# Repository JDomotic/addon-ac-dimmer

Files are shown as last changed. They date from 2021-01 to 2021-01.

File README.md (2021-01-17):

# AC Dimmer Addon
This is a custom made 2 channel AC dimmer addon which fits on the back of the [Wireless sensor board](https://github.com/JDomotic/esp12-wireless-sensor-board) .

The board can receive commands over uart with configurable transition speed per channel. 
It also has a 230VAC button input and a 230VAC power meter

## Version 1 | 05-01-2019
**Features**:
* Onboard 1A 3.3v AC power supply
* Zero cross detection 
* Two triac for 230VAC dimming with a total power of 4 amps (or 2*2 amps)
* Input for a 230VAC button 
* 230VAC power meter  
* Small formfactor, fits in electric wall boxes 

**Schematic**

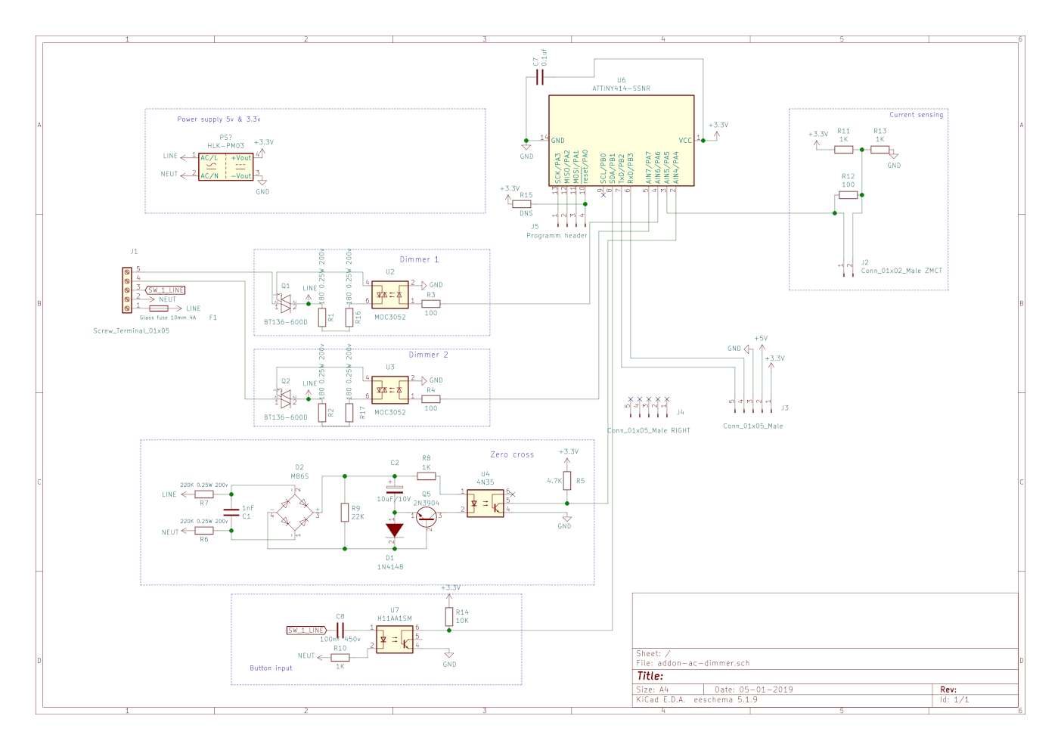
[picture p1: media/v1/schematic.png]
Schematic V1


**BOM**

**Ref**|**Qnty**|**Value**|**Footprint**|**Vendor (LCSC)**
:-----: | :-----: | :-----: | :-----: | :-----:
C1,|1|1nF|Capacitor\_SMD:C\_1206\_3216Metric\_Pad1.42x1.75mm\_HandSolder|C152975
C2,|1|10uF/10V|Capacitor\_THT:CP\_Radial\_D4.0mm\_P2.00mm|C191532
C7,|1|0.1uf|Capacitor\_SMD:C\_1206\_3216Metric\_Pad1.42x1.75mm\_HandSolder|C128353
C8,|1|100nF 450v|Capacitor\_SMD:C\_1206\_3216Metric\_Pad1.42x1.75mm\_HandSolder|C106025
D1,|1|1N4148|Diode\_SMD:D\_SOD-123|C184882
D2,|1|MB6S|Package\_TO\_SOT\_SMD:TO-269AA|C83867
F1,|1|Glass fuse 10mm 4A|Resistor\_THT:R\_Axial\_DIN0411\_L9.9mm\_D3.6mm\_P12.70mm\_Horizontal|C140492
J1,|1|Screw\_Terminal\_01x05|TerminalBlock\_RND:TerminalBlock\_RND\_205-00279\_1x05\_P5.00mm\_Vertical|C163149
J1,|1|Screw\_Terminal\_01x05|TerminalBlock\_RND:TerminalBlock\_RND\_205-00279\_1x05\_P5.00mm\_Vertical|C163148
J2,|1|Conn\_01x02\_Male ZMCT|Connector\_PinHeader\_2.54mm:PinHeader\_1x02\_P2.54mm\_Vertical|-
J3,|1|Conn\_01x05\_Male|Connector\_PinHeader\_2.54mm:PinHeader\_1x05\_P2.54mm\_Vertical|-
J4,|1|Conn\_01x05\_Male RIGHT|Connector\_PinHeader\_2.54mm:PinHeader\_1x05\_P2.54mm\_Vertical|-
J5,|1|Programm header|Connector\_PinHeader\_2.54mm:PinHeader\_1x04\_P2.54mm\_Vertical|-
Q1, Q2,|2|BT136-600D|Package\_TO\_SOT\_THT:TO-220-3\_Vertical|C130426
Q1, Q2,|2|TO-220 heatsink|TO-220 heatsink|C4650
Q5,|1|2N3904|Package\_TO\_SOT\_SMD:SOT-23|C18536
R1, R2, R16, R17,|4|180 0.25W 200v|Resistor\_SMD:R\_1210\_3225Metric\_Pad1.42x2.65mm\_HandSolder|C171148
R3, R4, R12,|3|100|Resistor\_SMD:R\_0805\_2012Metric\_Pad1.15x1.40mm\_HandSolder|-
R5,|1|4.7K|Resistor\_SMD:R\_0805\_2012Metric\_Pad1.15x1.40mm\_HandSolder|C328399
R6, R7,|2|220K 0.25W 200v|Resistor\_SMD:R\_0805\_2012Metric\_Pad1.15x1.40mm\_HandSolder|C352118
R8, R11, R13,|3|1K|Resistor\_SMD:R\_0805\_2012Metric\_Pad1.15x1.40mm\_HandSolder|C95781
R9,|1|22K|Resistor\_SMD:R\_0805\_2012Metric\_Pad1.15x1.40mm\_HandSolder|-
R10,|1|1K|Resistor\_SMD:R\_1206\_3216Metric\_Pad1.30x1.75mm\_HandSolder|C175514
R14,|1|10K|Resistor\_SMD:R\_0805\_2012Metric\_Pad1.15x1.40mm\_HandSolder|C103904
R15,|1|DNS|Resistor\_SMD:R\_0805\_2012Metric\_Pad1.15x1.40mm\_HandSolder|C103904
U1,|1|HLK-PM02|Power\_Supply:HLK-PM03| 
U2, U3,|2|MOC3052|Package\_DIP:SMDIP-6\_W7.62mm|C115471
U4,|1|4N35|Package\_DIP:SMDIP-6\_W7.62mm|C115444
U6,|1|ATTINY414-SSNR|Package\_SO:SOIC-14\_3.9x8.7mm\_P1.27mm|C189365
U7,|1|H11AA1SM|Package\_DIP:SMDIP-6\_W7.62mm|C184383

**Render**

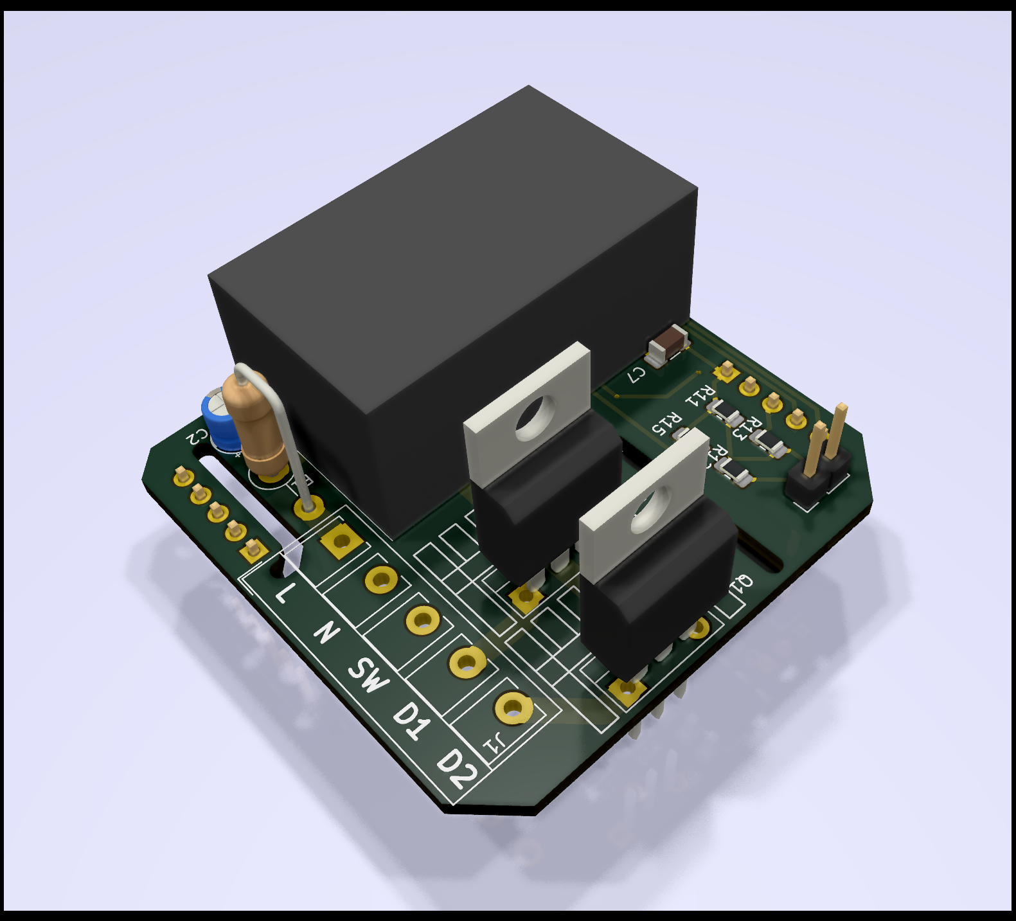
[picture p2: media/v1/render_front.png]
Render front

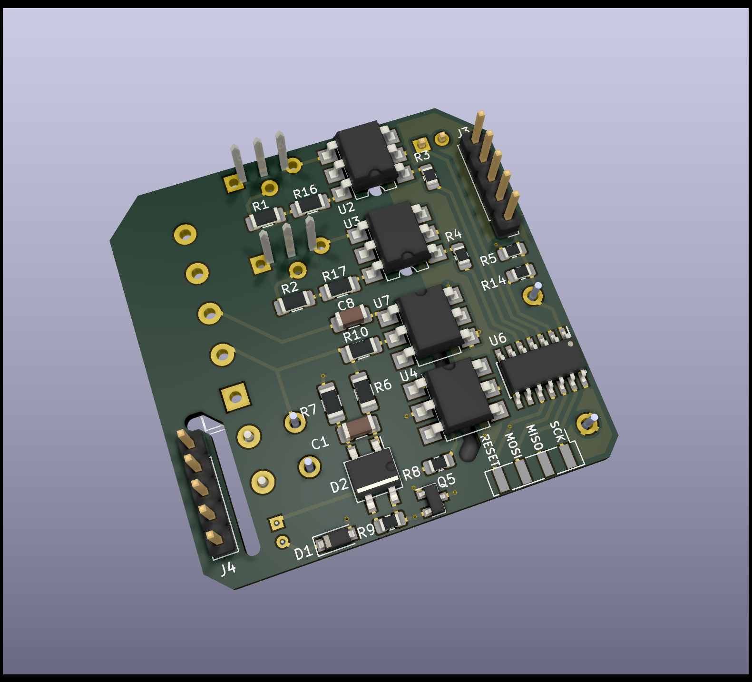
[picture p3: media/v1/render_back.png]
Render back


**Assembled**

Assembeled with 1 triac (lower height):
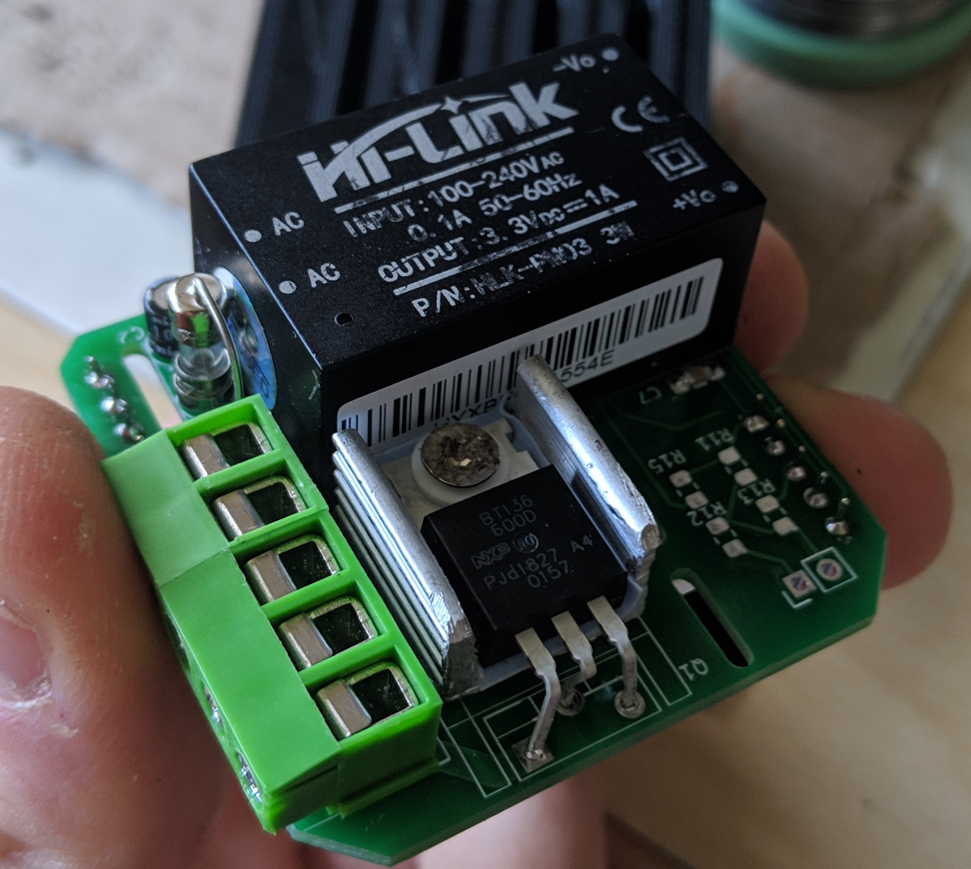
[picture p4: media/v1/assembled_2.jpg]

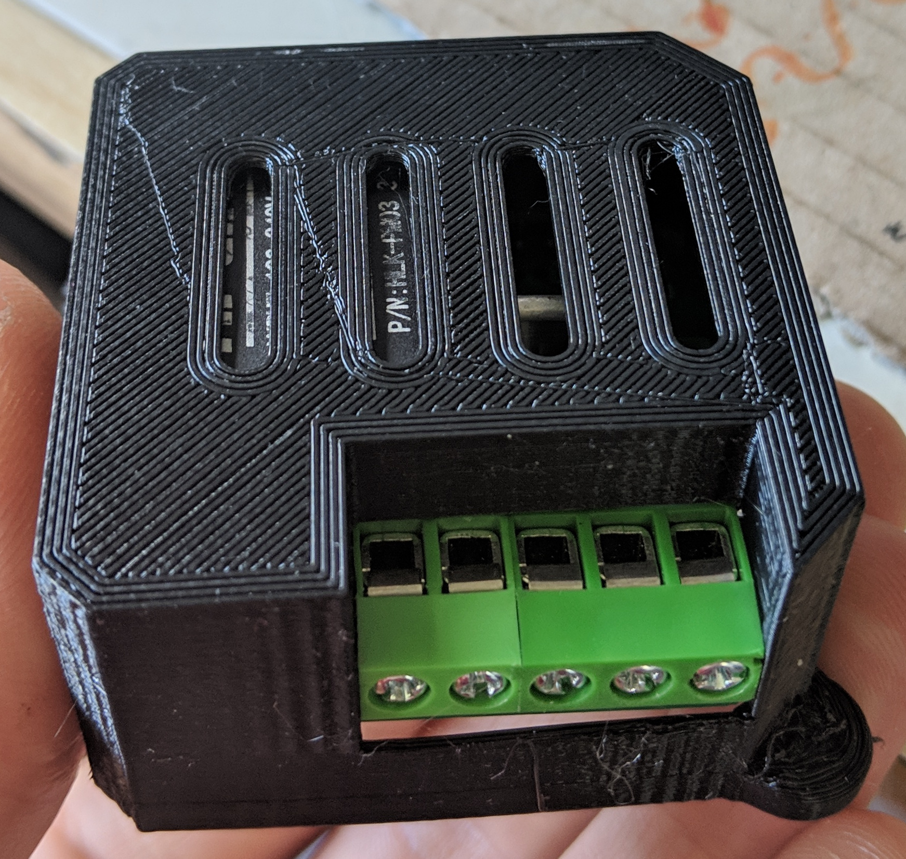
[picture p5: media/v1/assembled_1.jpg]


Assembeled with 2 triacs:
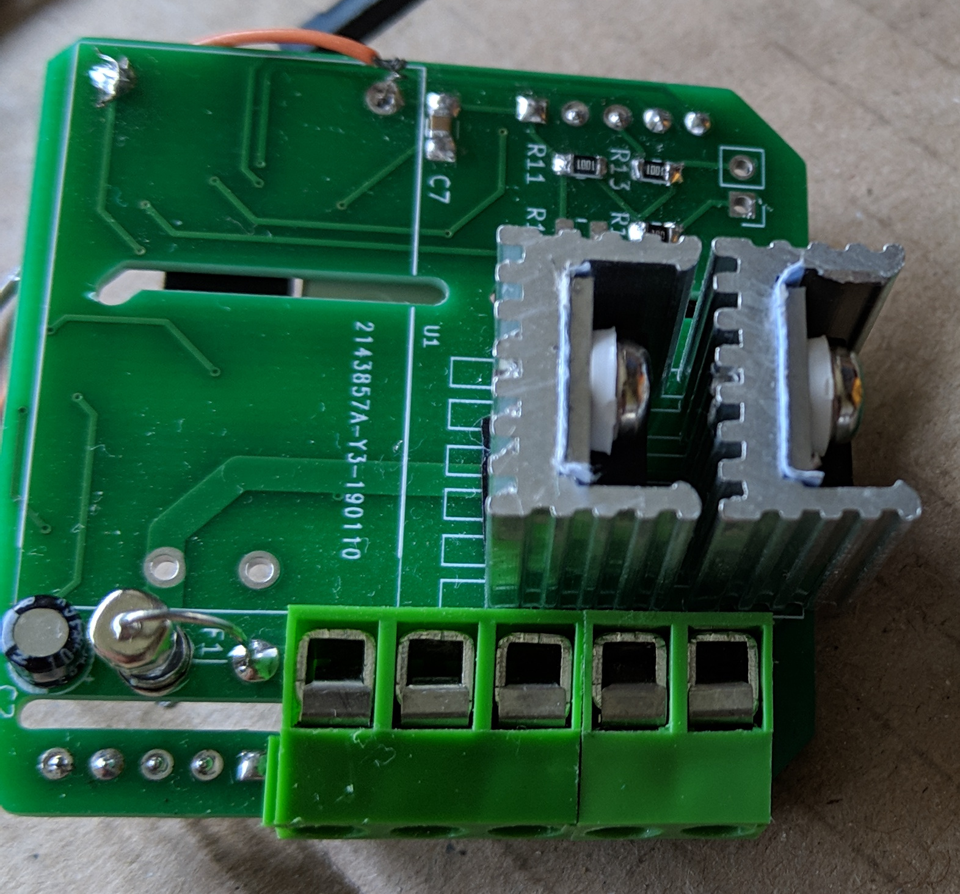
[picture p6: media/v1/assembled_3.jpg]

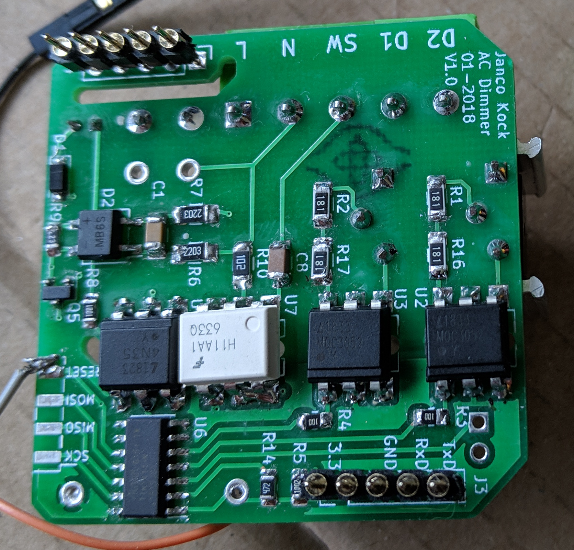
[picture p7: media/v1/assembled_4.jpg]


**Issues**

There are a few issues with the board: 
1. The wrong SOT-23 footprint is used. Due this, the transistor Q5 needs to be soldered upside down (This because pin 1 and 2 are flipped) 
2. R14 and R5 references are swapped on the PCB silkscreen. 
3. Due a fault in the schematic, the button input cannot work. To fix this, leg number 6 of U7 must be cut off and pad 5 and 6 should be soldered together.

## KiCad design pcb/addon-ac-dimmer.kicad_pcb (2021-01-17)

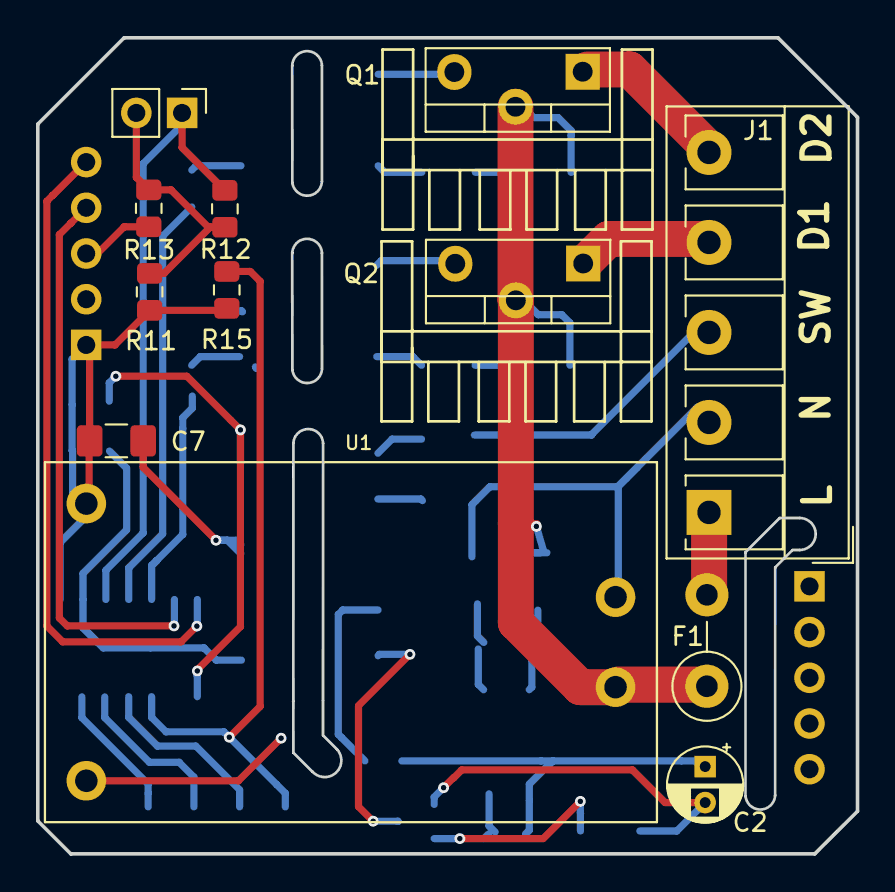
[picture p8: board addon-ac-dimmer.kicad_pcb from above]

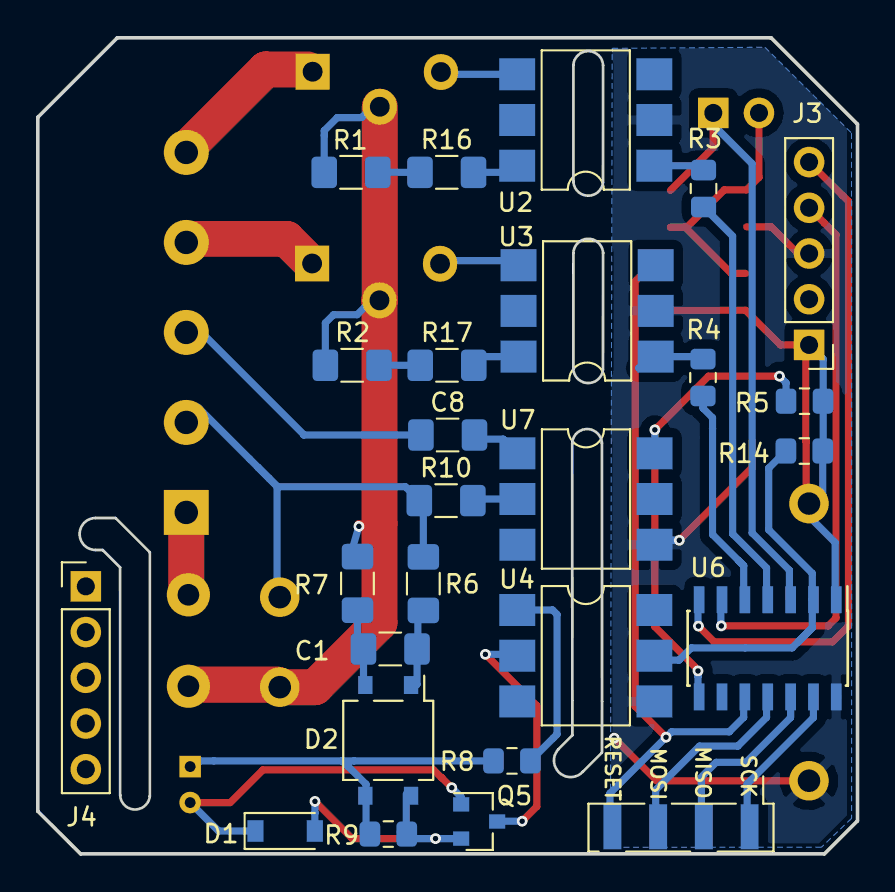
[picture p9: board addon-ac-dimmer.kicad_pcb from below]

Board: 2 copper layers, 45.5 x 45.3 mm, 38 parts (26 on the bottom side), 37 nets.

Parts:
C1: 1nF; C_1206_3216Metric_Pad1.42x1.75mm_HandSolder
C2: 10uF/10V; CP_Radial_D4.0mm_P2.00mm
C7: 0.1uf; C_1206_3216Metric_Pad1.42x1.75mm_HandSolder
C8: 100nF; C_1206_3216Metric_Pad1.42x1.75mm_HandSolder
D1: 1N4148; D_SOD-123
D2: MB6S; TO-269AA
F1: Glass fuse 10mm 4A; R_Axial_DIN0411_L9.9mm_D3.6mm_P5.08mm_Vertical
J1: Screw_Terminal_01x05; TerminalBlock_RND_205-00279_1x05_P5.00mm_Vertical
J2: Conn_01x02_Male ZMCT; PinHeader_1x02_P2.54mm_Vertical
J3: Conn_01x05_Male; PinHeader_1x05_P2.54mm_Vertical
J4: Conn_01x05_Male RIGHT; PinHeader_1x05_P2.54mm_Vertical
J5: Programm header; PinHeader_1x04_P2.54mm_Vertical_SMD_Pin1Left
Q1, Q2: BT136-600D; TO-220-3_Vertical
Q5: 2N3904; SOT-23
R1, R16: 180; R_1206_3216Metric_Pad1.42x1.75mm_HandSolder
R2, R17: 360; R_1206_3216Metric_Pad1.42x1.75mm_HandSolder
R3, R4: 100; R_0805_2012Metric_Pad1.15x1.40mm_HandSolder
R5: 4.7K; R_0805_2012Metric_Pad1.15x1.40mm_HandSolder
R6, R7: 220K; R_1206_3216Metric_Pad1.42x1.75mm_HandSolder
R8, R11, R13: 1K; R_0805_2012Metric_Pad1.15x1.40mm_HandSolder
R9: 22K; R_0805_2012Metric_Pad1.15x1.40mm_HandSolder
R10: 1K; R_1206_3216Metric_Pad1.42x1.75mm_HandSolder
R12: 50; R_0805_2012Metric_Pad1.15x1.40mm_HandSolder
R14, R15: 10K; R_0805_2012Metric_Pad1.15x1.40mm_HandSolder
U1: HLK-PM02; HLK-PM03
U2, U3: MOC3052; SMDIP-6_W7.62mm
U4: 4N35; SMDIP-6_W7.62mm
U6: ATTINY414-SSNR; SOIC-14_3.9x8.7mm_P1.27mm
U7: H11AA1SM; SMDIP-6_W7.62mm

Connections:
+3V3: C7.2, J3.1, R5.1, R11.2, R14.2, R15.2, U1.4, U6.1
GND: C7.1, J3.3, R13.1, U1.3, U2.2, U3.2, U4.4, U6.14, U7.4
LINE: F1.1, Q1.2, Q2.2, R1.2, R2.2, R7.2, U1.1
NEUT: J1.2, R6.2, R10.1, U1.2
unnamed: C1.1, D2.1, R6.1
unnamed: C1.2, D2.2, R7.1
unnamed: C2.1, D2.3, R8.2, R9.1
unnamed: C2.2, D1.1, Q5.1
unnamed: C8.2, U7.1
unnamed: D1.2, D2.4, Q5.2, R9.2
unnamed: F1.2, J1.1
unnamed: J1.4, Q2.1
unnamed: J1.5, Q1.1
unnamed: J2.1, R12.2, U6.3
unnamed: J2.2, R11.1, R12.1, R13.2
unnamed: J3.4, U6.6
unnamed: J3.5, U6.7
unnamed: J5.1, U6.13
unnamed: J5.2, U6.12
unnamed: J5.3, U6.11
unnamed: J5.4, R15.1, U6.10
unnamed: Q1.3, U2.4
unnamed: Q2.3, U3.4
unnamed: Q5.3, U4.2
unnamed: R1.1, R16.1
unnamed: R3.1, U6.4
unnamed: R3.2, U2.1
unnamed: R4.1, U6.5
unnamed: R4.2, U3.1
unnamed: R5.2, U4.5, U6.2
unnamed: R8.1, U4.1
unnamed: R10.2, U7.2
unnamed: R14.1, U6.8, U7.6
unnamed: R16.2, U2.6
unnamed: R2.1, R17.1
unnamed: R17.2, U3.6
SW_1_LINE: C8.1, J1.3

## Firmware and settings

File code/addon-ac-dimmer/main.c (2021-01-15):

/*
 * GccApplication1.c
 *
 * Created: 20-1-2019 15:04:12
 * Author : atmel
 */				
#define F_CPU 10000000UL
#define BAUD_RATE 115200
#define USART0_BAUD_RATE ((float)F_CPU * 64) / (16 * (float)BAUD_RATE)

#define TO_AC(zc_steps) (F_CPU/4/2)/zc_steps
#define IDENTIFIER 'Q'
#define DIMMER_SCALE_VALUE 10000L

#include <avr/io.h>
#include <avr/interrupt.h>
#include <stdbool.h>
#include <string.h>
#include <stdio.h>
#include <util/delay.h>

// UART methods
int8_t USART_init();
uint8_t USART_read();
void USART_write(const uint8_t data);
void printString(const char myString[]);

volatile uint16_t steps_between_zc; 

long dimmer_channel_1_level = 255*DIMMER_SCALE_VALUE;
long dimmer_channel_1_fade_step_value = 0;
int dimmer_channel_1_fade_steps = 0;

long dimmer_channel_2_level = 255*DIMMER_SCALE_VALUE;
long dimmer_channel_2_fade_step_value = 0;
int dimmer_channel_2_fade_steps = 0;

bool button_input = false;

char uart_msg[4] = {0};
uint8_t uart_msg_position = 0;
volatile bool new_message = false;
///
/// Timer A - Compare 0 - Dimmer channel 1
///
ISR(TCA0_CMP0_vect){
	// Turn TRIAC channel 1 on, only if ZC is within specs and dimmer level is not near the ZC
	if(steps_between_zc > 20000 && dimmer_channel_1_level < 250*DIMMER_SCALE_VALUE)
		PORTA.OUT |= (1 << 7);
	// Clear interrupt flag
	TCA0.SINGLE.INTFLAGS = TCA_SINGLE_CMP0_bm;
} 

///
/// Timer A - Compare 1 - Dimmer channel 2
///
ISR(TCA0_CMP1_vect){
	// Turn TRIAC channel 2 on, only if ZC is within specs and dimmer level is not near the ZC
	if(steps_between_zc > 20000 && dimmer_channel_2_level < 250*DIMMER_SCALE_VALUE)
		PORTA.OUT |= (1 << 6);
	// Clear interrupt flag
	TCA0.SINGLE.INTFLAGS = TCA_SINGLE_CMP1_bm;
}

///
/// Zero cross falling edge interrupt
///
ISR(PORTA_PORT_vect){
	// Turn off timer
	//TCA0_SINGLE_CTRLA = 0b00000100;

	// Measure time between ZC
	steps_between_zc = TCA0.SINGLE.CNT;
	
	// Calculate new fade value
	if(dimmer_channel_1_fade_steps != 0){
		dimmer_channel_1_fade_steps--;
		dimmer_channel_1_level += dimmer_channel_1_fade_step_value;
	}
	if(dimmer_channel_2_fade_steps != 0){
		dimmer_channel_2_fade_steps--;
		dimmer_channel_2_level += dimmer_channel_2_fade_step_value;
	}
	
	// Calculate compare values for dimmer channels
	uint16_t channel_0 = steps_between_zc * (dimmer_channel_1_level/DIMMER_SCALE_VALUE)/255;
	uint16_t channel_1 = steps_between_zc * (dimmer_channel_2_level/DIMMER_SCALE_VALUE)/255;
	TCA0.SINGLE.CMP0 = channel_0;
	TCA0.SINGLE.CMP1 = channel_1;
	
    if(dimmer_channel_1_level == 0){// Triac 1 ON
		TCA0.SINGLE.INTCTRL &= ~(1 << TCA_SINGLE_CMP0_bp);	// CMP 0 off
		PORTA.OUT |= (1 << 7);
	}else{
		TCA0.SINGLE.INTCTRL |= (1 << TCA_SINGLE_CMP0_bp);	// CMP 0 on
		PORTA.OUT &= ~(1 << 7);
	}
			
    if(dimmer_channel_2_level == 0){// Triac 1 ON
		TCA0.SINGLE.INTCTRL &= ~(1 << TCA_SINGLE_CMP1_bp);	// CMP 1 off
		PORTA.OUT |= (1 << 6);
	}else{
		TCA0.SINGLE.INTCTRL |= (1 << TCA_SINGLE_CMP1_bp);	// CMP 1 on
		PORTA.OUT &= ~(1 << 6);
	}
			
	// Check button input
	button_input = !((PORTB.IN >> 1) & 1);
	
	// Clear interrupt flag
	PORTA_INTFLAGS |= (1 << 4);
		
	// Reset timer
	TCA0.SINGLE.CNT = 0;
		
	// Enable timer
	//TCA0_SINGLE_CTRLA = 0b00000101;
}

///
/// Timer B for UART package timeout check
///
ISR(TCB0_INT_vect){
	// Timeout between UART package occurs. Reset channel
	uart_msg_position = 0;
	// Disable
	TCB0_CTRLA = 0b00000010;
	// Clear interrupt flag
	TCB0_INTFLAGS = 0b00000001;
	// Write 'out of sync' package
	USART_write(IDENTIFIER);
}

///
/// UART methods
///
ISR(USART0_RXC_vect){
	uart_msg[uart_msg_position] =  USART0.RXDATAL;
	
	// Update package is done, so reset the UART package channel to 0
	if(uart_msg_position == 3){
		new_message = true;
		uart_msg_position = 0;
		
		// Disable package timeout timer
		TCB0.CNT = 0;
		TCB0_CTRLA = 0b00000010;
	} else{
		uart_msg_position++;
		
		// Enable package timeout timer.
		TCB0.CNT = 0;
		TCB0_CTRLA = 0b00000011;
	}
}

int8_t USART_init(){
	int8_t sigrow_val = SIGROW.OSC20ERR3V; // read signed error
	int32_t baud_reg_val = USART0_BAUD_RATE;
	baud_reg_val *= (1024 + sigrow_val); // sum resolution + error
	baud_reg_val /= 1024; // divide by resolution
	USART0.BAUD = (int16_t) baud_reg_val;
	
	// Enable receive interrupt 
	USART0.CTRLA = 0b10000000;
  
	USART0.CTRLB = 0 << USART_MPCM_bp       /* Multi-processor Communication Mode: disabled */
	| 0 << USART_ODME_bp     /* Open Drain Mode Enable: disabled */
	| 1 << USART_RXEN_bp     /* Receiver enable: enabled */
	| USART_RXMODE_NORMAL_gc /* Normal mode */
	| 0 << USART_SFDEN_bp    /* Start Frame Detection Enable: disabled */
	| 1 << USART_TXEN_bp;    /* Transmitter Enable: enabled */

	USART0.CTRLC = USART_CMODE_ASYNCHRONOUS_gc /* Asynchronous Mode */
	| USART_CHSIZE_8BIT_gc /* Character size: 8 bit */
	| USART_PMODE_DISABLED_gc /* No Parity */
	| USART_SBMODE_1BIT_gc; /* 1 stop bit */

	return 0;
}

uint8_t USART_read()
{
	while (!(USART0.STATUS & USART_RXCIF_bm));
	return USART0.RXDATAL;
}

void USART_write(const uint8_t data)
{
	while (!(USART0.STATUS & USART_DREIF_bm));
	USART0.TXDATAL = data;
}

void printString(const char myString[]) {
	uint8_t i = 0;
	while (myString[i]) {
		USART_write(myString[i]);
		i++;
	}
}

int main(void)
{
	///
	/// CPU clock settings
	///
	
	// Disable change protection
	CPU_CCP = 0xD8;
	
	// Set main pre-scaler division to 2 (so 20mhz / 2 = 10mhz)
	CLKCTRL_MCLKCTRLB = 0b00000001;
	
	// Lock the registers again
	CLKCTRL_MCLKLOCK = 1;
	
	// Set TX pin high
	PORTB_OUT = 0b00000100;
	
	// PB1 input (button), RX input and TX as output
	PORTB_DIR = 0b00000100;
	// PA5 input (current), PA4 input (zc), PA6/7 output (triac)
	PORTA_DIR = 0b11000000;
	
	// Turn TRIAC channel 1&2 off
	PORTA.OUT &= ~(1 << 7);
	PORTA.OUT &= ~(1 << 6);

	
	// Generate zero cross input interrupt on falling edge
	PORTA_PIN4CTRL = 0x3;
	
	USART_init();	
	
	///
	/// Timer A for zero cross timing
	///
	
	// Enable timer A and set division to 4 .
	TCA0_SINGLE_CTRLA = 0b00000101;
	// Enable compare channel 1 and 2 interrupt
	//TCA0.SINGLE.INTCTRL = 1 << TCA_SINGLE_CMP0_bp  | 1 << TCA_SINGLE_CMP1_bp

	///
	/// Timer B for UART package timeout check
	///
	
	// Set tcb0 top
	TCB0.CCMP = 0xffff;
	// Set to timeout check mode
	TCB0_CTRLB = 0b00000000;
	// Enable interrupt
	TCB0.INTCTRL = 0b000000000000000000000000000000000000000000000001;
	
	// Enable all interrupt
	sei();

	for(;;){
		if(new_message){
			new_message = false;
			long scaled_level;
			
			scaled_level =  DIMMER_SCALE_VALUE * (255-uart_msg[0]);
			dimmer_channel_1_fade_step_value = (scaled_level - dimmer_channel_1_level) / (uart_msg[2] * 4);
			dimmer_channel_1_fade_steps = uart_msg[2] * 4;
			
			scaled_level =  DIMMER_SCALE_VALUE * (255-uart_msg[1]);
			dimmer_channel_2_fade_step_value = (scaled_level - dimmer_channel_2_level) / (uart_msg[3] * 4);
			dimmer_channel_2_fade_steps = uart_msg[3] * 4;
		}else{
			continue;
		}
	
		
		_delay_ms(1);
		//char test[50];
		//sprintf(test,"%u - %u - %u \n\r", steps_between_zc, TCA0.SINGLE.CMP0, TCA0.SINGLE.CMP1);
		//printString(test);
	}

}
